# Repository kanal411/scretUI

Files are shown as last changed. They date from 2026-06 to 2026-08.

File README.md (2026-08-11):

# scretUI
A 3D-printed smartphone case with a 4.2" e-ink display for Samsung Galaxy A55 5G.

## Features:
The screen displays:
- current time (+/- 5 minutes)
- 7 hour weather forecast with dynamic icons
- to-do list
- current date
- simple animated landscape that changes based on weather conditions (sun moves across the sky, 1–10 clouds slowly drift across the scene)

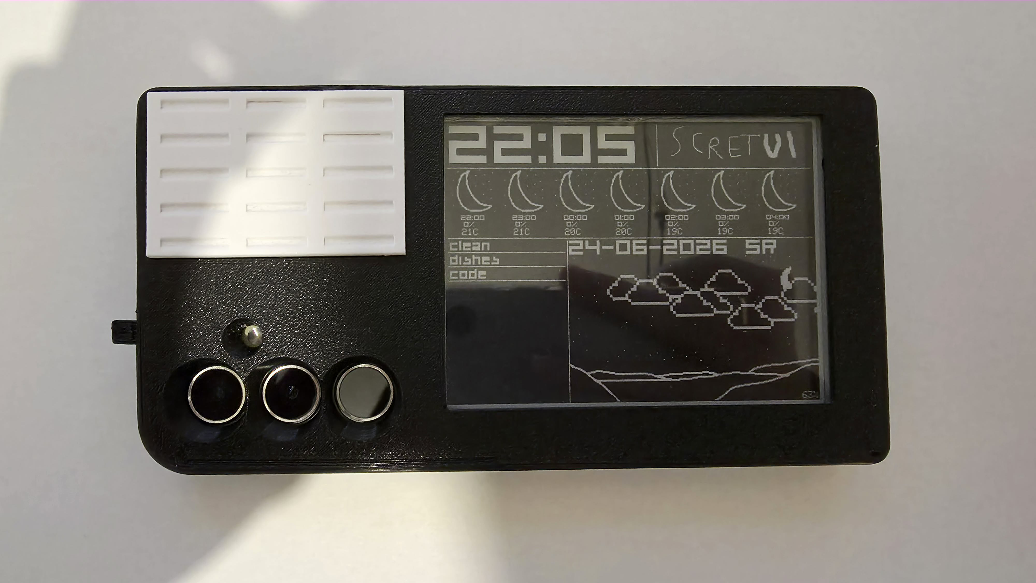
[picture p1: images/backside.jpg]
  
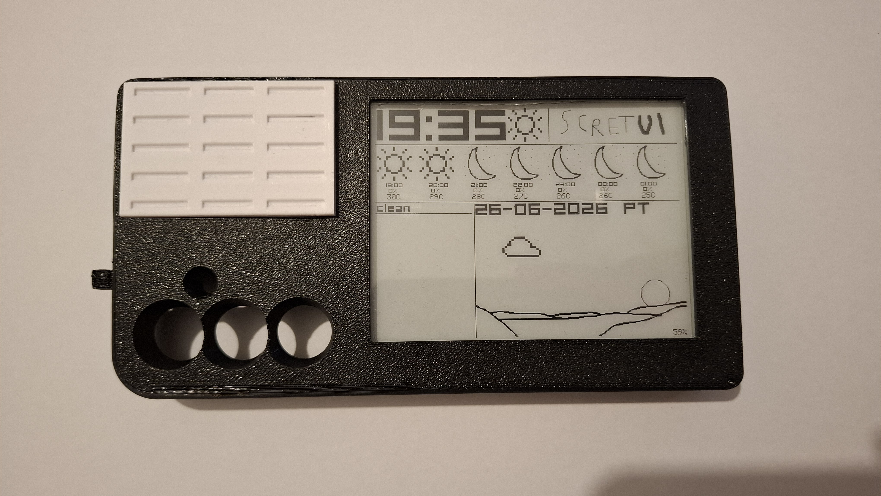
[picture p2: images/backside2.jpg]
  

## Used parts:
- waveshare 13353
- xiao seed esp32 s3
- 100k ohm resistor
- 220k ohm resistor
- 1500mAh 3.7V Li-Pol battery (50x34x8mm)
- 9x8x8mm button
- 92x70x1.5mm polycarbonate sheet
  
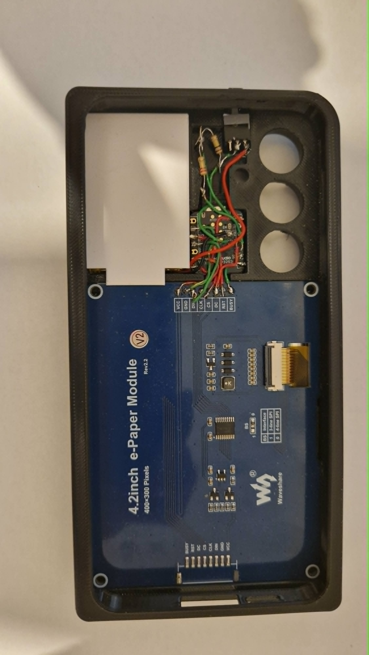
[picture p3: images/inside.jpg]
Inside


## How it works:
The phone connects to the ESP32 via BLE. The mobile app fetches weather data (Open-Meteo API), then sends it along with:
- current time
- date
- to-do list
- next wake-up interval

The ESP32 updates the e-ink display and then enters deep sleep for the requested period. The cycle then repeats.

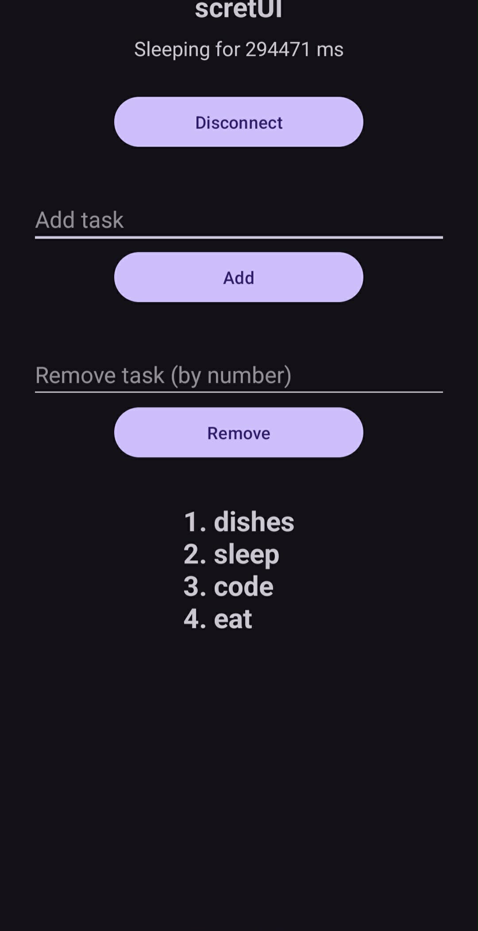
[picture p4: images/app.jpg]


## How to make:
The phone case is printed in TPU 90A with 15% infill, while the battery enclosure is printed in PETG. Install Arduino IDE, then go to Preferences and add https://espressif.github.io/arduino-esp32/package_esp32_index.json in “Additional Boards Manager URLs”, open Boards Manager and install the ESP32 package by Espressif Systems, select the ESP32-S3 board (e.g. ESP32S3 Dev Module) under Tools, set Tools → CPU Frequency to 80MHz, connect the ESP32-S3 board to your computer via USB, choose the correct COM/tty port, then paste the code from esp32Code into the Arduino sketch, after which you can click Upload.

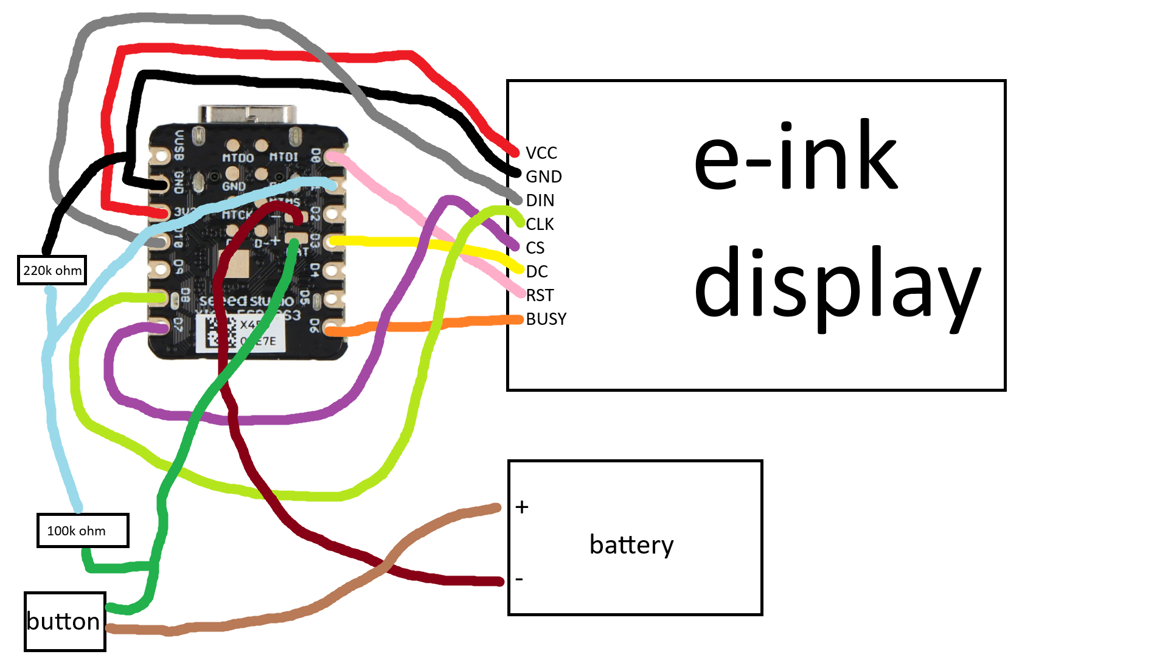
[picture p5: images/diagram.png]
Diagram


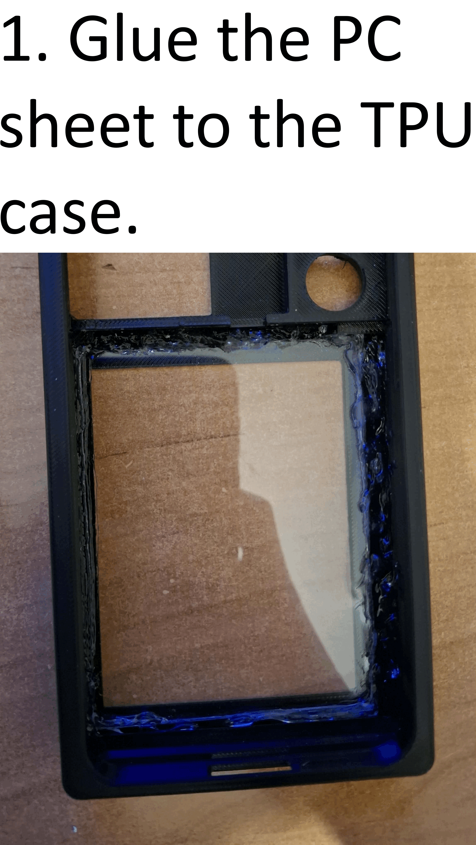
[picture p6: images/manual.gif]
Manual


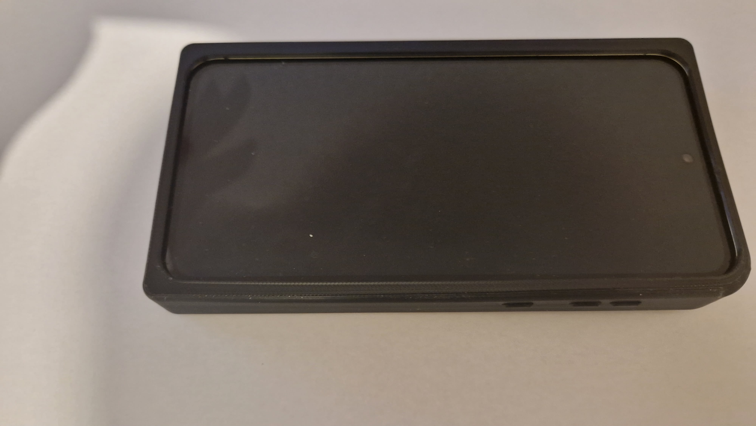
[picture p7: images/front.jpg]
Back view


### AI usage:
AI was used for writing some auxiliary functions, assisting with Kotlin development and BLE integration, and supporting debugging.

### .STEP file
I can't include .step file because this model wasn't created in CAD software.

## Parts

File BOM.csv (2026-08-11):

Item Name | Qty | Price (total) (USD) | Example item link | Notes
waveshare 13353 | 1 | $35.47 | https://pl.aliexpress.com/item/1005004260969887.html | I bought it from local reseller for cheaper so I reccomend to look for cheaper options then aliexpress
xiao seed esp32 s3 | 1 | $12.88 | https://pl.aliexpress.com/item/1005012775225959.html | It's important to buy board with integrated li-po battery charging.
100k ohm resistor + 220k ohm resistor | 1 | - | - | You can skip these if reporting battery charge level isn't important for you.
1500mAh 3.7V Li-Pol battery (50x34x8mm) | 1 | $6.30 | https://pl.aliexpress.com/item/1005008334647452.html
8x8mm locking button | 1 | $1.46 | https://pl.aliexpress.com/item/1005005959433891.html | The price is for 10 pcs
92x70x1.5mm polycarbonate sheet | 1 | $8.89 | https://pl.aliexpress.com/item/1005009018470808.html | This is 100x100mm one, you will need tools to cut it to size
Total Price (USD): | $65.00

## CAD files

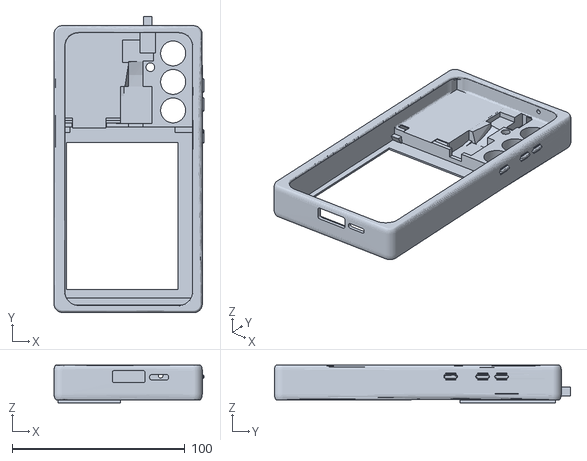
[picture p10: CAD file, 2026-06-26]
caseAndBatHousing.stl
86.9 x 171.6 x 21.9

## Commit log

2026-06-26 Code for ESP32
2026-08-11 Bill Of Materials
    [BOM.csv]
